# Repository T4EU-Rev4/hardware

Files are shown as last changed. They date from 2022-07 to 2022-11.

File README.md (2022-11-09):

# hardware
Collection of the hardware items used in the train project
All schematics and pcbs are made with KiCAD https://www.kicad.org/ 

## Node
Here are the schematic and the pcb files of a small controller board located. This board can be used as a I2C client but also supports RS485 if necessary.

## Node_MP3
This folder contains the schematic and the software for the wagon DK MP3, witch contains a small mp3 player.

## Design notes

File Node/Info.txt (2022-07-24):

Pin	Name

J2	D6

J3	D2
J4	D3
J5	D4
J6	D5

J7	D7
J8	D8
J9	D9
J10	D10

J19	A0
J20	A1
J21	A2
J22	A3	
J23	A4
J24	A5
J25	A6
J26	A7

J11	MOSI
J12	MISO
J13	SCK
J18	AREF

J14	RX1
J15	TX1

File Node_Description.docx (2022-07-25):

Wagon Controller

# 1 Hardware

This small device can be used

a) as a replacement of the PCF8575 16 Bit I²C bus expander. In this mode, the RS485-Transceiver will not be used. The socket for this chip can be left open, R1..R6 are not needed.
b) as a node on a RS485-Network. Based on this physical layer, a ModBus-Client will be placed. ModBus is a very famous protocol, widely used in industry. Libraries for Arduino are also available. It allows a much more sophisticated control of the wagon, than a simple bus expander can provide.

The following description covers both scenarios.

## 1.1 Schematic

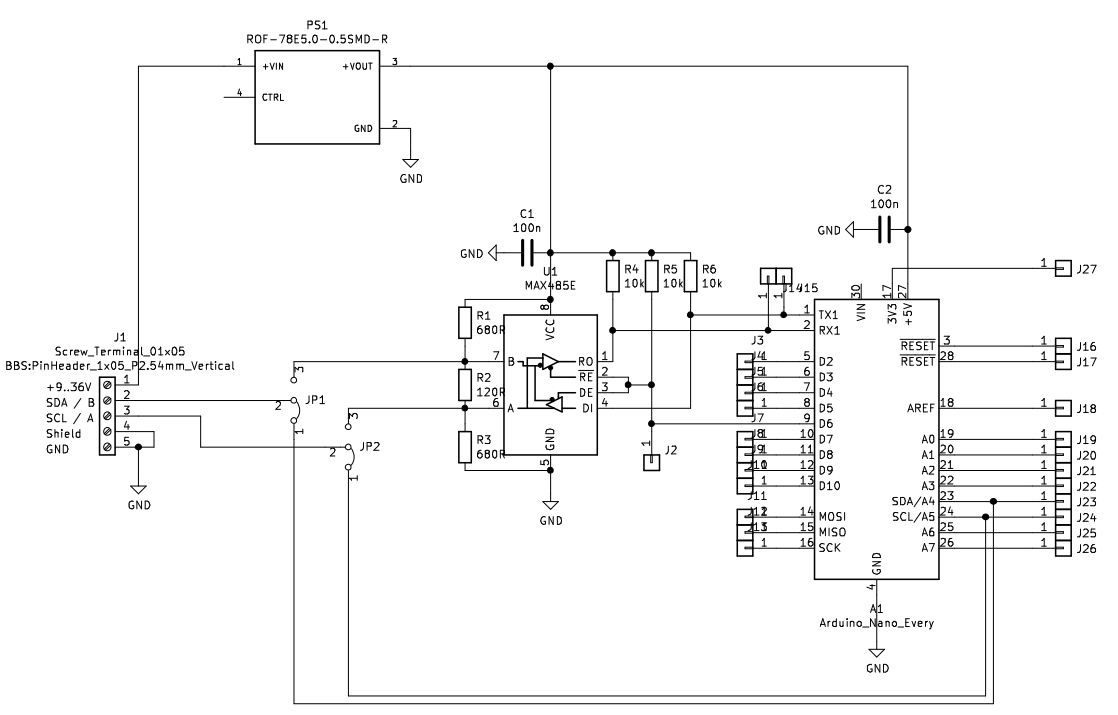
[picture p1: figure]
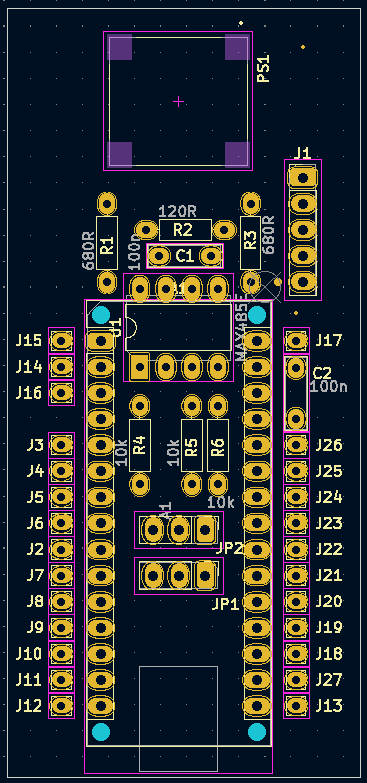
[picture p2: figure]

## 1.2 Board

To allow a small footprint, most of the parts were placed underneath the controller board. We do not use SMD packages to keep soldering simple.

The dimensions of the pcb are: 35 x 75 mm

FS1 | A Step-Down-Converter with a 5V / 500mA output and a wide input-range from 9V..36V. Using a DC-DC-Converter per node will eliminate noise coming along the main power supply from the loco. One power supply will fit all needs.
JP1, JP2 | These two jumpers connects terminal 2/3 to either the RS485 device or the SDL/SCL lines of the Controller. The jumpers must only be changed, if the firmware at the node changes. 1-2 = I²C mode 2-3 = RS485 mode
Address | To spare I/O-pins, the address of the device must be set via source code. In RS485-mode, it will be possible to change the address via ModBus protocol.
R1,R3 | They provide a save potential at the lines A and B, if no sender is active. These resistors are only for safe operation and must not be placed several times. Place them at the first node in the chain.
R2 | Terminating resistor. Must correspond with the impedance of the wires. 120 Ohm will fit most needs. Needed only at the beginning and the end of the bus.

Schematic as well as the board were made with KiCAD, with is available for free.

KiCad EDA - Schematic Capture & PCB Design Software (https://www.kicad.org/)

# 2 Software

## 2.1 PCF8575 replacement

The PCF8575 is a 16Bit port expander for the I²C-Bus. A maximum of 8 devices can be used per I²C bus. More devices requires the use of an I²C multiplexer.

Because of the lack of internal configuration registers (like MCP23016), the device is quite simple. After the initial write sequence transporting the device address, every subsequent byte written will be placed in the output latch A bevor B. The operation is module 2. Writing 6 bytes will have the same result then writing only the last 2 bytes.

The firmware to emulate the PCF8575 is based on the WIRE library, which comes with Arduino. The idea is to be able to replace a PCF8575 without making any changes to the I²C-Master. Just setting the correct address at the slave. The address must be set in the source code and can not be changed by external settings like the PCF8575 can.

The controller board used here comes with real push-pull-outputs, where the PCF8575 uses only low-side switches.

The Controller used is an Arduino Nano Every. It is cheap, has a small footprint and supports 2 serial ports by Hardware, so one can be used for serial monitor and the other is used for RS485 device transceiver.

The Arduino-Pins are assigned to the bits of the PCF8575 and the PCB connectors as follows:

PCF8575 Register A | Arduino Pin-Nr | Connector @ PCB | Connector @ PCB | Arduino Pin-Nr | PCF8575 Register B
Bit 0 | 2 | J3 (D2) | J10 (D10) | 10 | Bit 0
Bit 1 | 3 | J4 (D3) | J11 (D11,MOSI) | 11 | Bit 1
Bit 2 | 4 | J5 (D4) | J12 (D12,MISO) | 12 | Bit 2
Bit 3 | 5 | J6 (D5) | J13 (D13,SCK) BuiltIn-LED | 13 | Bit 3
Bit 4 | 6 | J2 (D6) | J19 (A0) | A0 | Bit 4
Bit 5 | 7 | J7 (D7) | J20 (A1) | A1 | Bit 5
Bit 6 | 8 | J8 (D8) | J21( A2) | A2 | Bit 6
Bit 7 | 9 | J9 (D9) | J22 (A3) | A3 | Bit 7
| | J14 (RX1) | J23 (A4/SDA) | A4
| | J15 (TX1) | J24 (A5/SCL) | A5
| | | J25 (A6) | A6
| | | J26 (A7) | A7
| | | J18 (AREF)
| | | J27 (+3V3)
| | | J13 (SCK)

The assignment is important for wiring the device. It can be easily changed in the firmware.
The Pin numbers are collected in two arrays, named portA and portB

uint8_t portA[] = {2, 3, 4, 5, 6, 7, 8, 9};

uint8_t portB[] = {10, 11, 12, 13, A0, A1, A2, A3};

## 2.2 RS485-Node

RS485 is a differential 2-wire bus system widely used in industry. It is the physical layer for a protocol named ModBus.

tbc

# 3 Sources

PCF8575 datasheet

https://www.ti.com/lit/gpn/PCF8575

MCP 23016 datasheet

https://ww1.microchip.com/downloads/en/DeviceDoc/20090C.pdf

RS485 Bus transceiver

https://datasheets.maximintegrated.com/en/ds/MAX1487-MAX491.pdf

Arduino Nano Every

https://docs.arduino.cc/hardware/nano-every

Used library for PCF8575

https://github.com/xreef/PCF8575_library

Arduino-Client for MQTT

https://github.com/knolleary/pubsubclient

JSON-Library for Arduino

https://github.com/bblanchon/ArduinoJson

F:\BBS\Schule\Projekte\Erasmus+\EEM4EU\data\Node_Description.docx Seite 2/3

Wagon Controller

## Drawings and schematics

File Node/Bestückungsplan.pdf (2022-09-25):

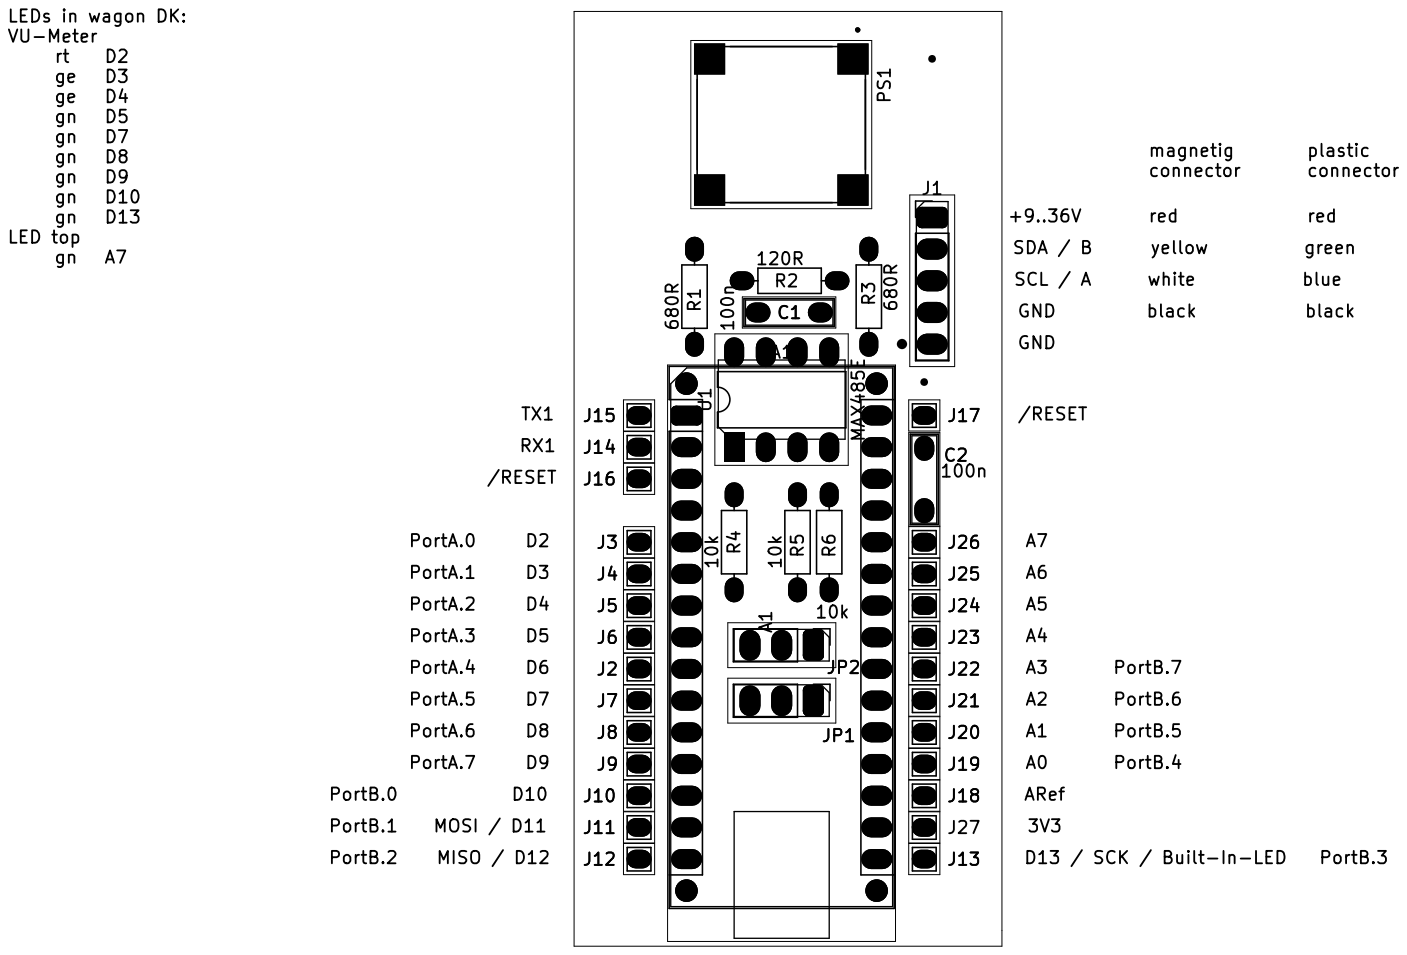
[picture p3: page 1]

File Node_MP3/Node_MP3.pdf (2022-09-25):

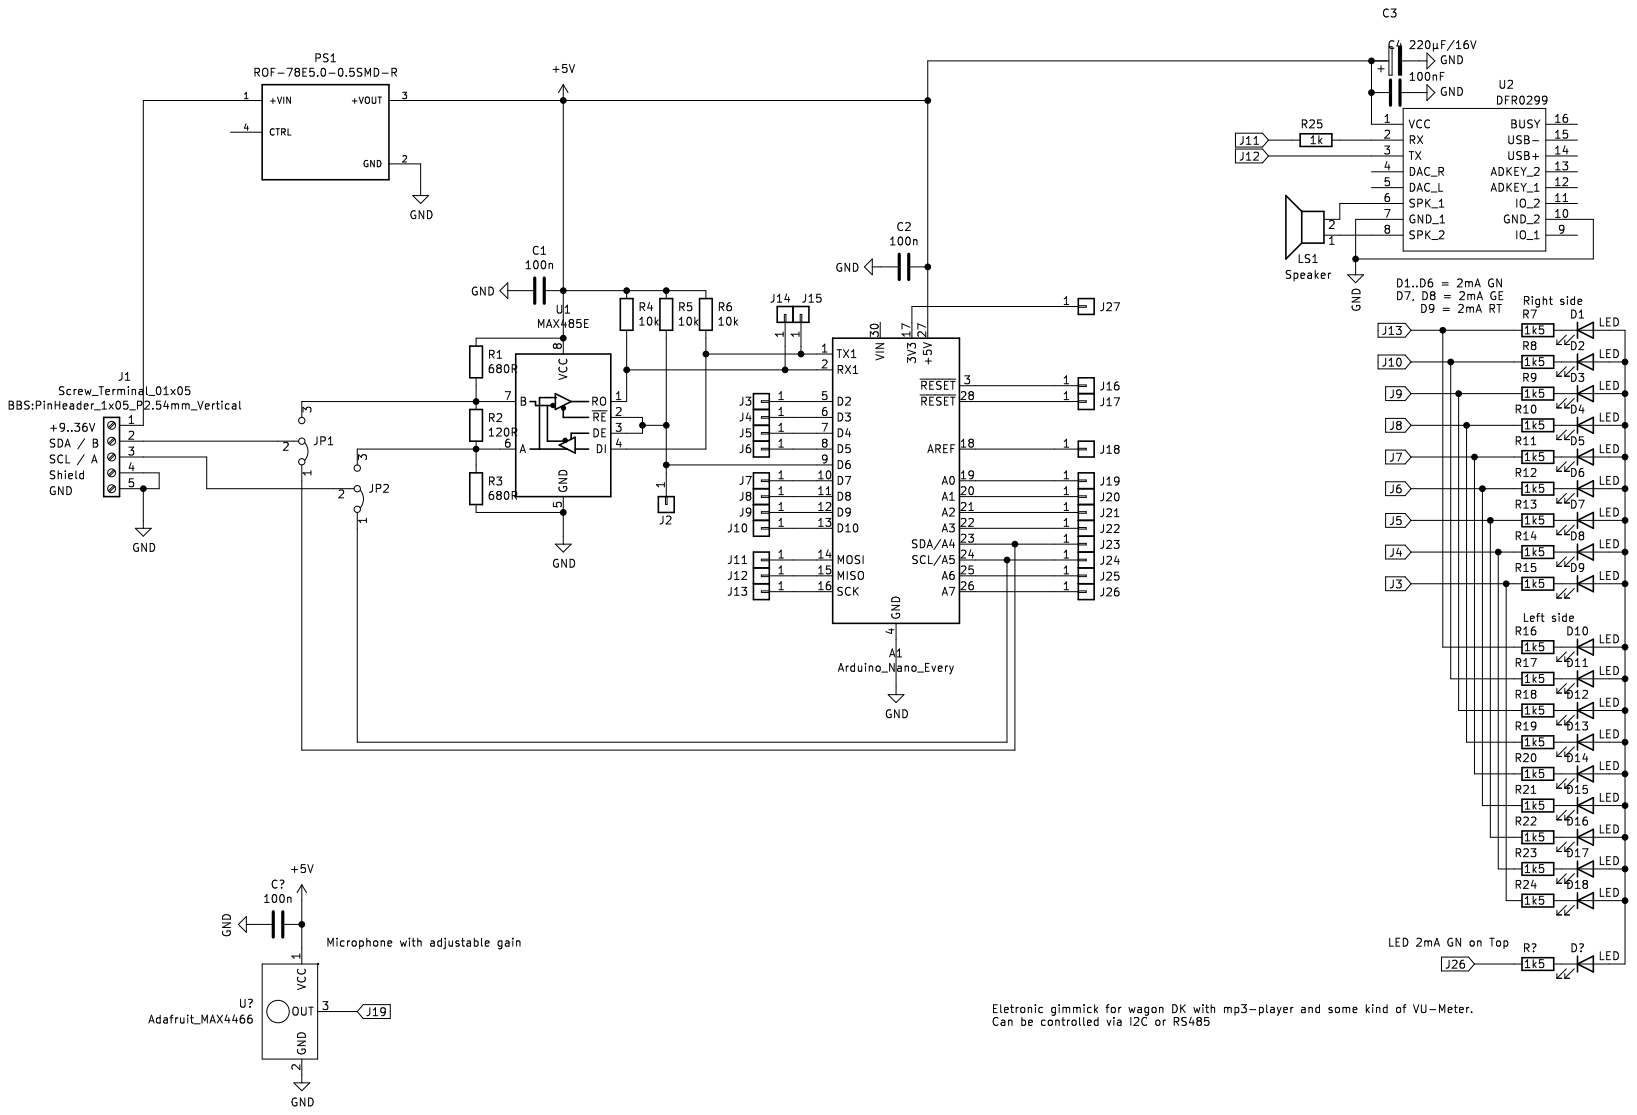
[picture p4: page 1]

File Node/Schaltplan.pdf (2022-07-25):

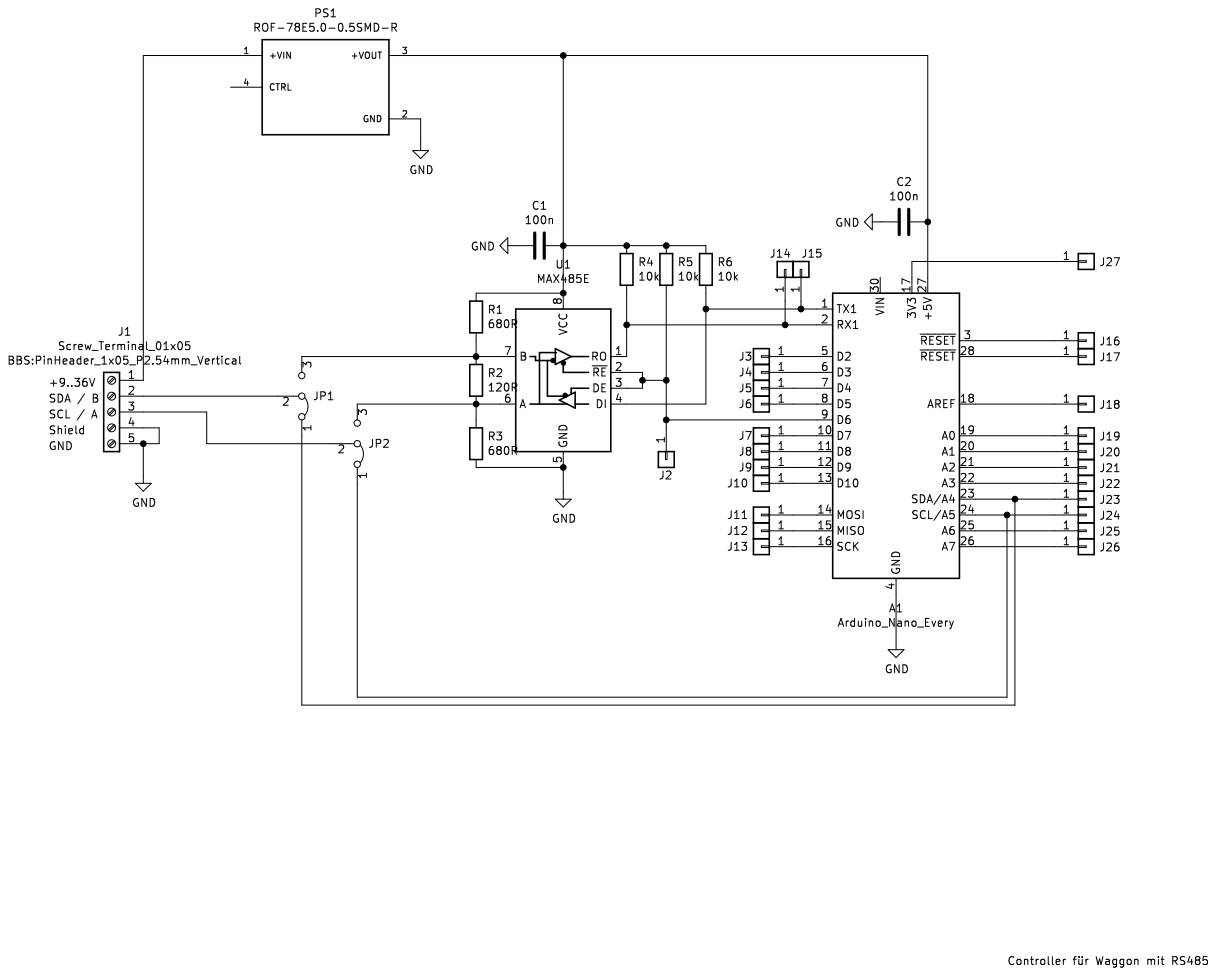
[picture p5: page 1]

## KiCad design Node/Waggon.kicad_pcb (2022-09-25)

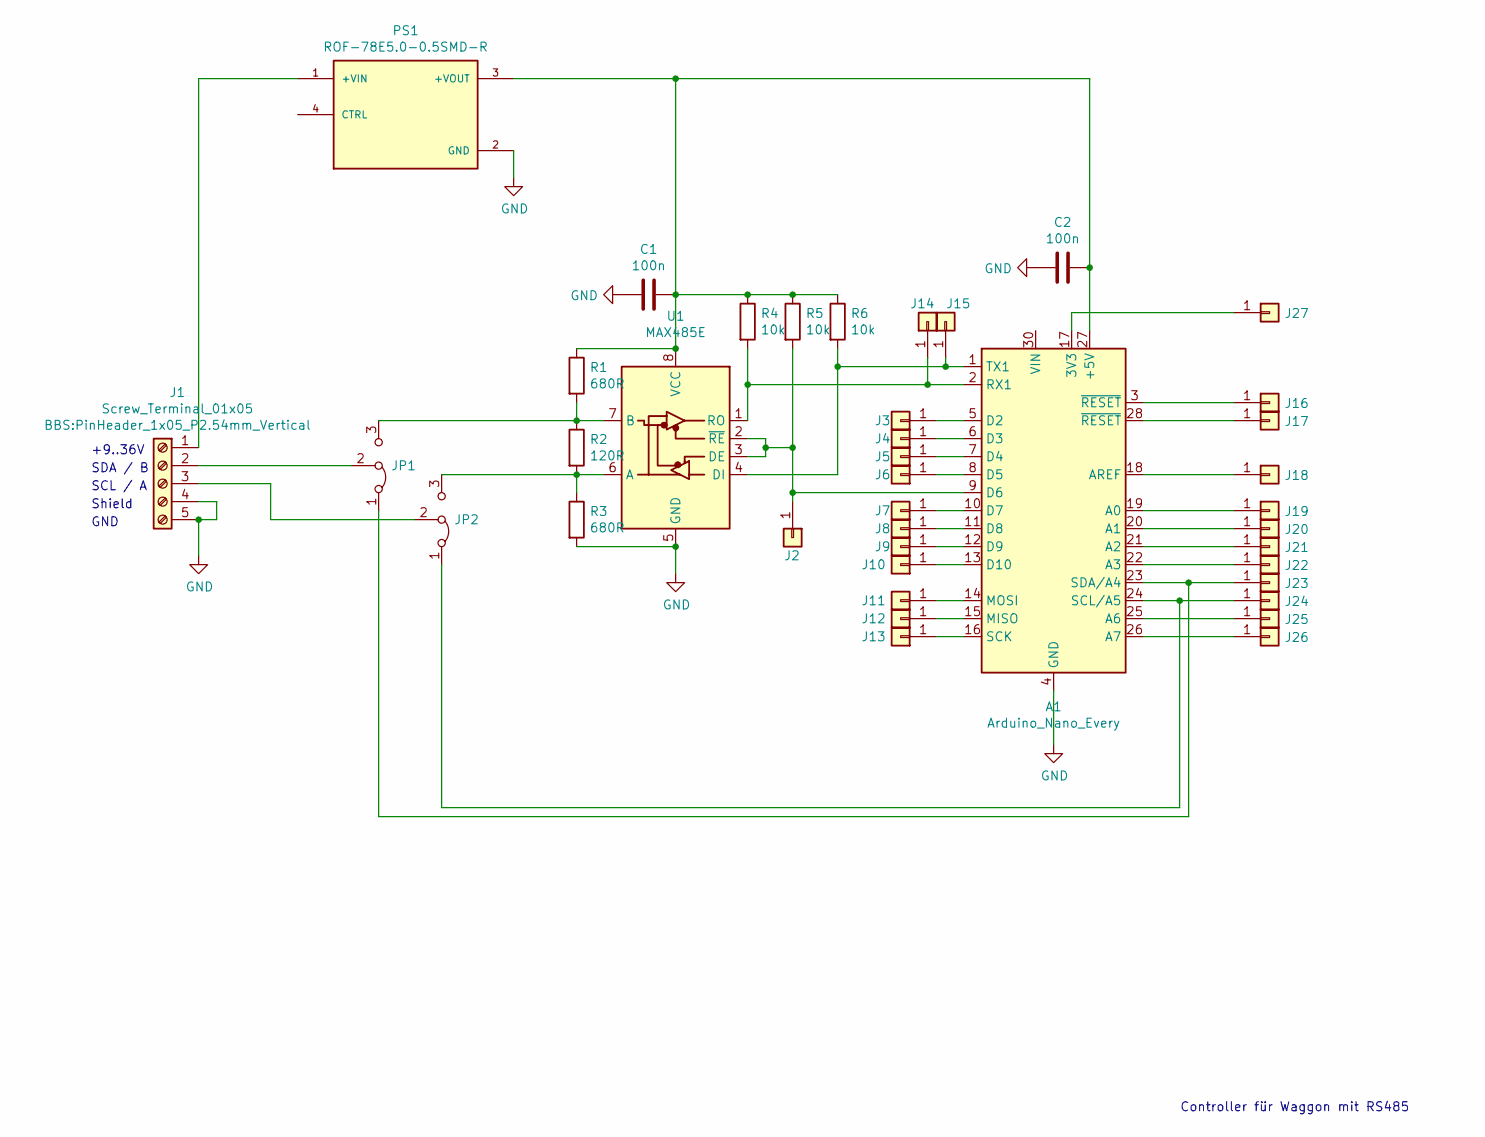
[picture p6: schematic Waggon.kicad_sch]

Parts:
A1: Arduino_Nano_Every; Arduino_Nano_WithMountingHoles
C1, C2: 100n; C_Rect_L7.0mm_W2.0mm_P5.00mm
J1: Screw_Terminal_01x05; PinHeader_1x05_P2.54mm_Vertical
J2, J3, J4, J5, J6, J7, J8, J9, J10, J11, J12, J13, J14, J15, J16, J17, J18, J19, J20, J21, J22, J23, J24, J25, J26, J27: Conn_01x01; TestPoint_THTPad_1.5x1.5mm_Drill0.7mm
JP1, JP2: Jumper_3_Bridged12; PinHeader_1x03_P2.54mm_Vertical
PS1: ROF-78E5.0-0.5SMD-R; CONV_ROF-78E5.0-0.5SMD-R; PARTREV 4
R1, R3: 680R; R_7.5
R2: 120R; R_7.5
R4, R5, R6: 10k; R_7.5
U1: MAX485E; DIP-8_W7.62mm_LongPads

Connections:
GND: A1.4 (GND), A1.29 (GND), C1.2, C2.1, J1.4, J1.5, PS1.2 (GND), R3.2, U1.5 (GND)
unnamed: A1.1 (TX1), J15.1, R6.2, U1.4 (DI)
unnamed: A1.2 (RX1), J14.1, R4.2, U1.1 (RO)
unnamed: A1.3 (~RESET), J16.1
unnamed: A1.5 (D2), J3.1
unnamed: A1.6 (D3), J4.1
unnamed: A1.7 (D4), J5.1
unnamed: A1.8 (D5), J6.1
unnamed: A1.9 (D6), J2.1, R5.2, U1.2 (~RE), U1.3 (DE)
unnamed: A1.10 (D7), J7.1
unnamed: A1.11 (D8), J8.1
unnamed: A1.12 (D9), J9.1
unnamed: A1.13 (D10), J10.1
unnamed: A1.14 (MOSI), J11.1
unnamed: A1.15 (MISO), J12.1
unnamed: A1.16 (SCK), J13.1
unnamed: A1.17 (3V3), J27.1
unnamed: A1.18 (AREF), J18.1
unnamed: A1.19 (A0), J19.1
unnamed: A1.20 (A1), J20.1
unnamed: A1.21 (A2), J21.1
unnamed: A1.22 (A3), J22.1
unnamed: A1.23 (SDA/A4), J23.1, JP1.1 (A)
unnamed: A1.24 (SCL/A5), J24.1, JP2.1 (A)
unnamed: A1.25 (A6), J25.1
unnamed: A1.26 (A7), J26.1
unnamed: A1.27 (+5V), C1.1, C2.2, PS1.3 (+VOUT), R1.1, R4.1, R5.1, R6.1, U1.8 (VCC)
unnamed: A1.28 (~RESET), J17.1
unnamed: J1.1, PS1.1 (+VIN)
unnamed: J1.2, JP1.2 (C)
unnamed: J1.3, JP2.2 (C)
unnamed: JP1.3 (B), R1.2, R2.1, U1.7 (B)
unnamed: JP2.3 (B), R2.2, R3.1, U1.6 (A)

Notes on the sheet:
+9..36V
Shield
SCL / A
Controller für Waggon mit RS485
SDA / B
GND

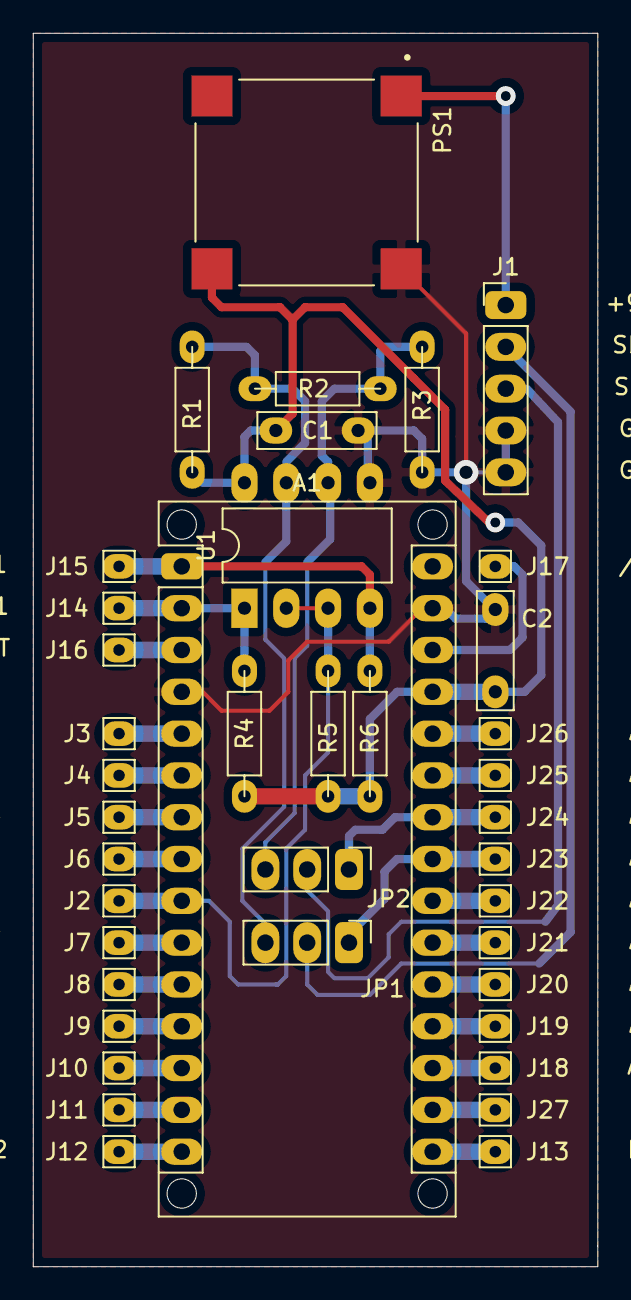
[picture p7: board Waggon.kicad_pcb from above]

Board: 2 copper layers, 34.3 x 74.9 mm, 40 parts (0 on the bottom side), 33 nets.

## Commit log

2022-07-24 This is the first version of a board capable to emulate the PCF8575 as well as communicate via RS485 to support a ModBus-Server oder ModBus-Client for example.
    [Waggon.kicad_pcb, Waggon.sch, Waggon_Nutzen.kicad_pcb]
2022-07-25 Adding KiCAD Footprints
    [Waggon.kicad_pcb, Waggon.kicad_sch]
2022-08-27 Schematic of Node-MP3
    [Waggon_MP3.kicad_sch]
2022-09-25 Updating Descriptions
    [Waggon.kicad_pcb]
